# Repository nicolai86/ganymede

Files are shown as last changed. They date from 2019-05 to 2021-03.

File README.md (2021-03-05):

# Ganymede
the Ganymede keyboard. An ARM based, split ergonomic keyboard.

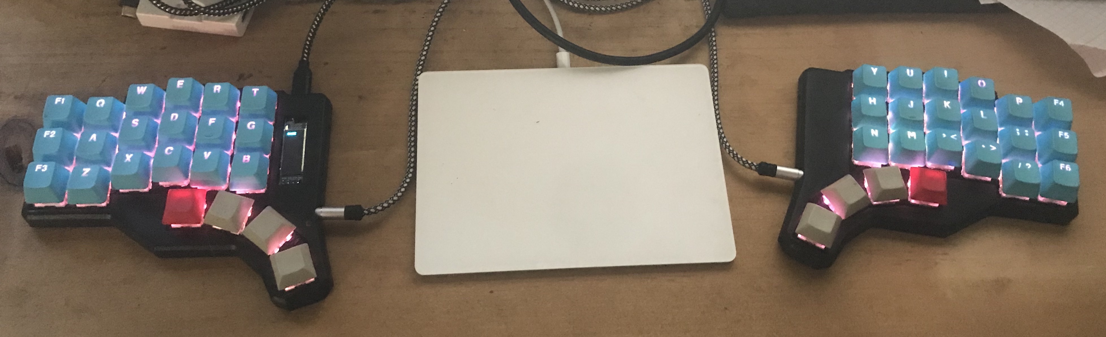
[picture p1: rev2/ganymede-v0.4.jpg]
current revision


## changelog 

### v0.5 / rev3

<ul style="list-style-type: none; margin: 0; padding: 0;">
    <li>+ choc support</li>
    <li>+ I2C eeprom (M24M01)</li>
    <li>- cherry mx support</li>
</ul>

### v0.4 / rev2

<ul style="list-style-type: none; margin: 0; padding: 0;">
    <li>+ per key RGB backlight</li>
    <li>+ 9 RGB underglow</li>
    <li>+ fully enclosed, 3d printable case with tenting support</li>
    <li>- flippable PCB</li>
</ul>

### v0.3 / rev1

<ul style="list-style-type: none; margin: 0; padding: 0;">
    <li>&#8226; OLED support (SSD1306 compatible)</li>
    <li>&#8226; ARM based (STM32F303CCT6)</li>
    <li>&#8226; QMK supported</li>
    <li>&#8226; flippable PCB</li>
    <li>&#8226; hot-swappable switches (using kailh-mx sockets)</li>
    <li>&#8226; mostly 0402 components</li>
</ul>

# qmk setup

- clone qmk 0.11.55
- add ganymede as a submodule: `git submodule add https://github.com/nicolai86/ganymede.git keyboards/ganymede`
- flash your ganymede: `make ganymede/rev3:default:dfu-util`

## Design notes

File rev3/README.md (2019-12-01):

# revision 0.5

There is no build guide for revision 0.5

## image

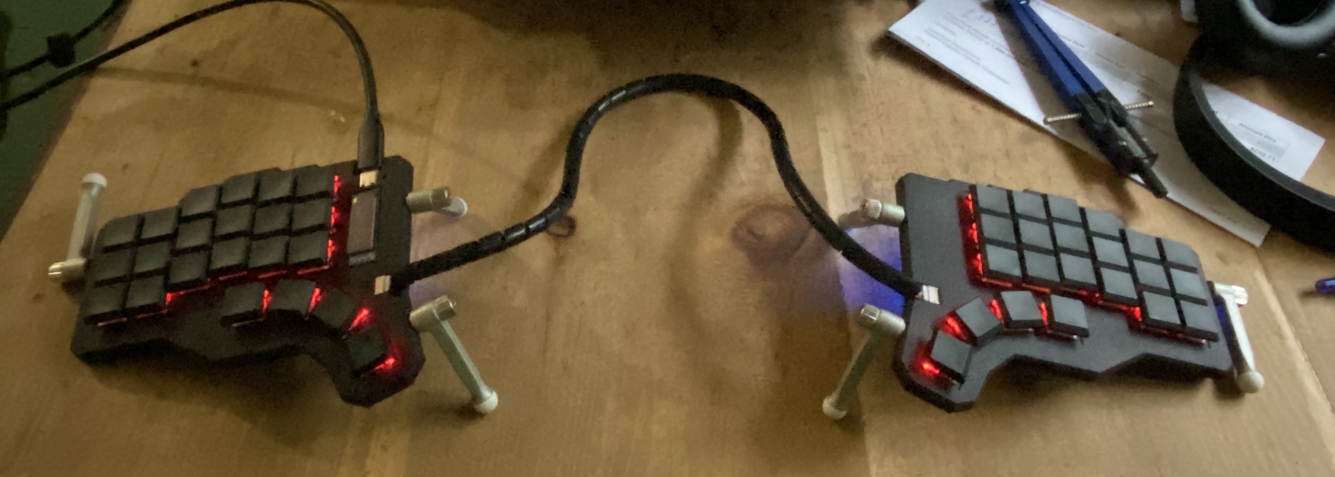
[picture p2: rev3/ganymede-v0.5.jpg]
left-right


## case

This revision comes with a fully enclosed case which can be 3d printed.
I've successfully 3d printed the case using SLS with Nylon 12:

However I need to update the existing case for the v0.5.1 PCB first

## gerbers

- [left side](./v0.5.1-left.zip)
- [right side](./v0.5.1-right.zip)

## BOM

- [left side](./v0.5.1-left.txt)
- [right side](./v0.5.1-right.txt)

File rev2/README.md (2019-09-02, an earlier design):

# revision 0.4

There is no build guide for revision 0.4 as it is mostly identical to revision 0.3;
The gerber files for this revision are available: [left hand (v0.4.1)](./left-0.4.1.zip) and [right hand (v0.4.0)](./right-0.4.0.zip).

## left side

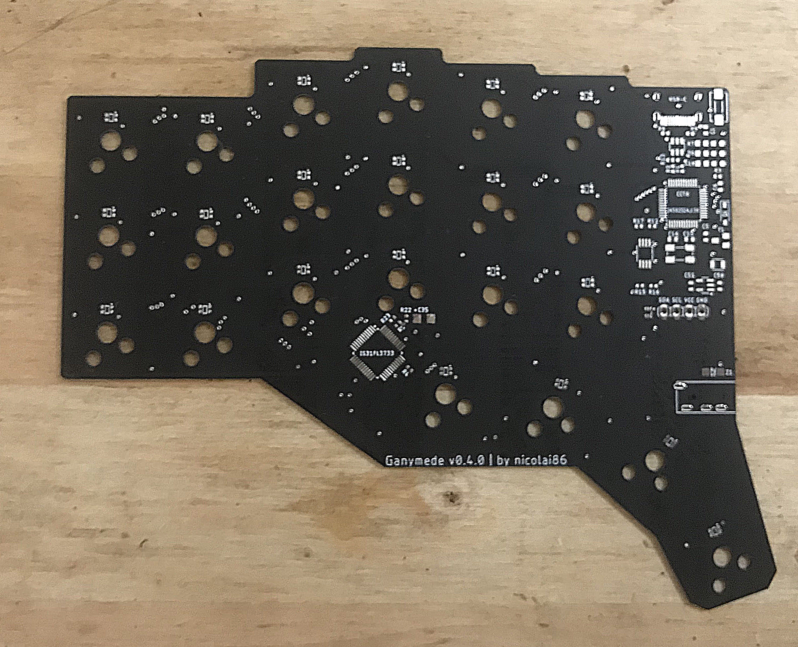
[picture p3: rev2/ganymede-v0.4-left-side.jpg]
left-top


## right side 

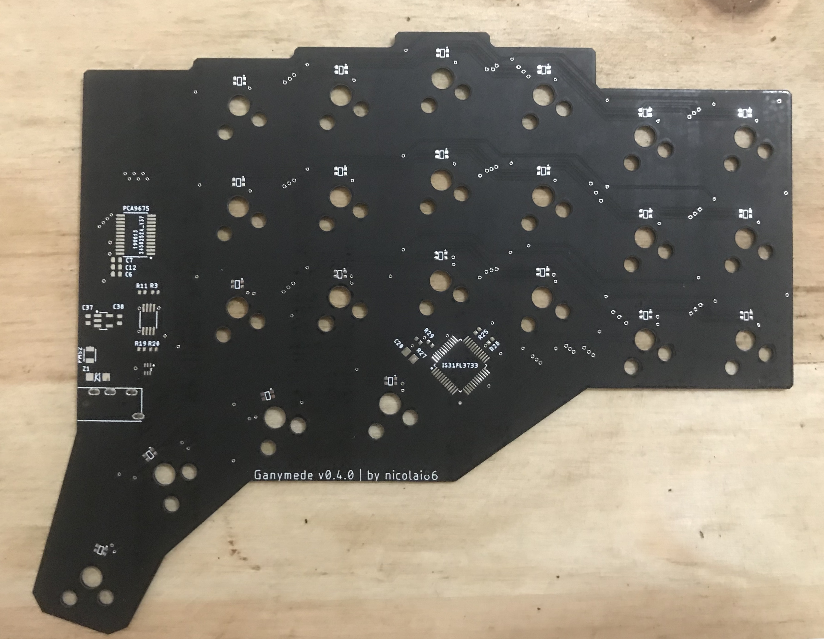
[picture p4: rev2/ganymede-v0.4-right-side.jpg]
right-top


## case

This revision comes with a fully enclosed case which can be 3d printed. [STL](./case-v0.4.zip).
I've successfully 3d printed the case using ABS with the following resolution and 100% infill each:

- [left top (100μm)](./case-v0.4/2-1x-left_upper-original.stl)
- [left bottom plate (200μm)](./case-v0.4/1-1x-left_plate-original.stl)
- [right top (100μm)](./case-v0.4/4-1x-right_upper-original.stl)
- [right bottom plate (200μm)](./case-v0.4/3-1x-right_plate-original.stl)

## Bill of Materials

- [left side](./ganymede-v0.4-left-side.bom.csv)
- [right side](./ganymede-v0.4-right-side.bom.csv)

You can find all parts on either lcsc.com or mouser.

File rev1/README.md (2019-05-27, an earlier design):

# revision 0.3

There is no build guide for rev 0.3 for now; See the assembled pictures for details; 
The gerber files for this revision are available in [gerber.zip](./gerber.zip).

Note that all decoupling capacitors are placed on the opposite side.

## left side (master)

### top

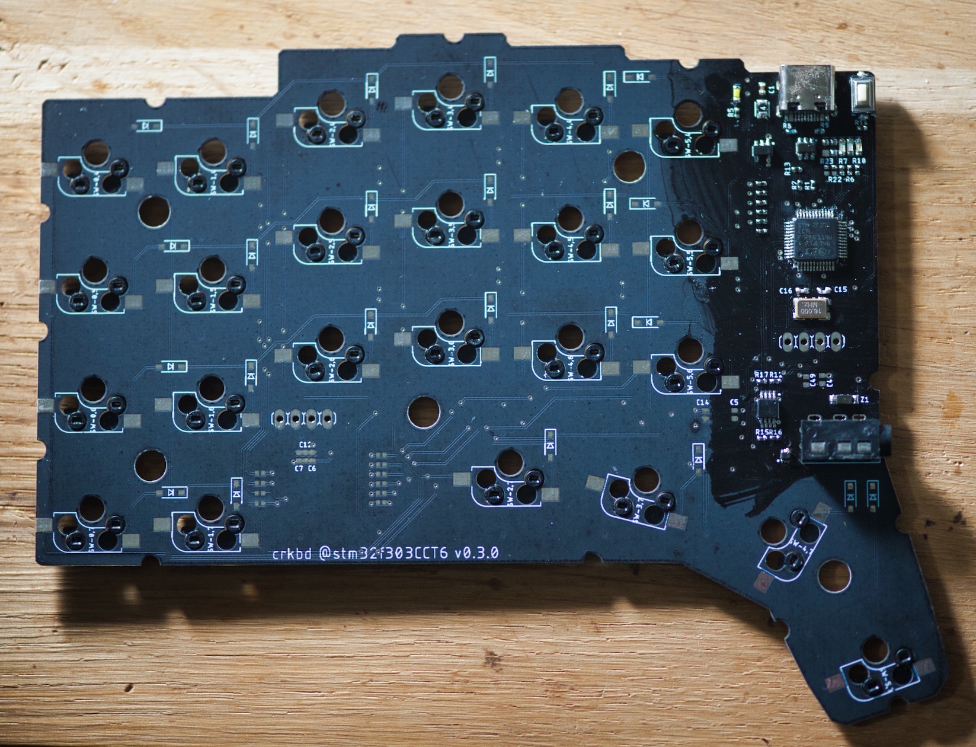
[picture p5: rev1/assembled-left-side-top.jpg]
left-top


important:
- capacitor for USB is placed on top
- resistors for primary I2C bus are placed on top
- resistors for the columns of the key matrix are placed on top

### bottom

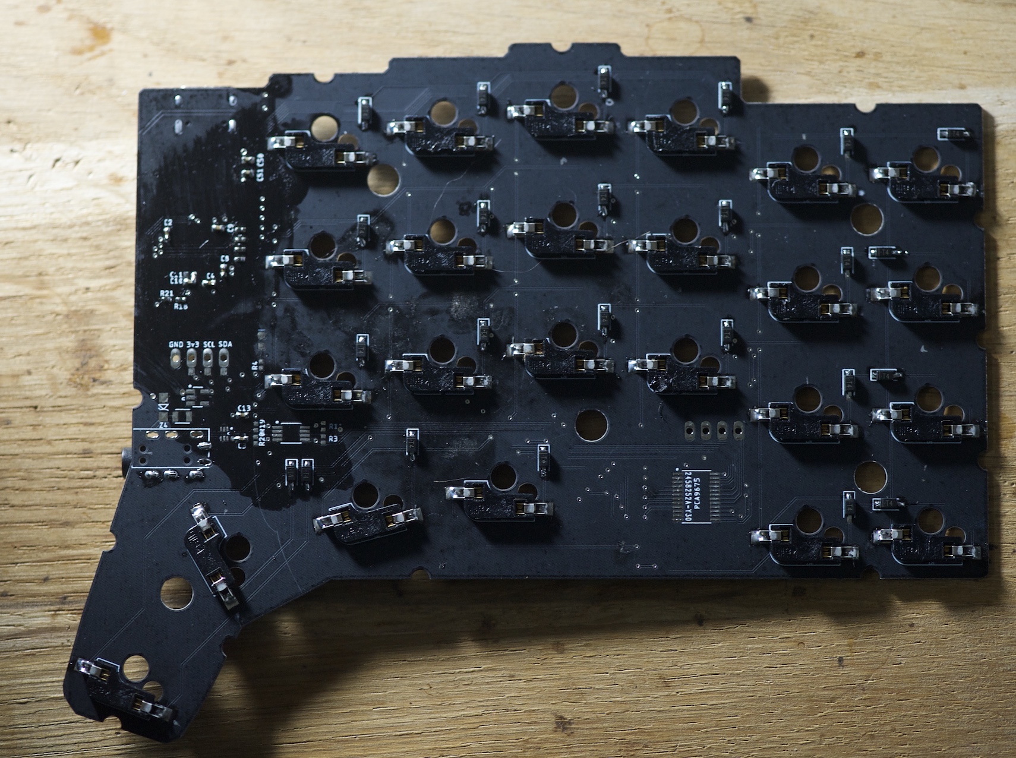
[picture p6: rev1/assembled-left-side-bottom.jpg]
left-bottom


important:
- all MX sockets are placed on the bottom
- all diodes are placed on the bottom
- capacitors for voltage regular are placed on the bottom
- capacitors for STM32F303 are placed on the bottom
- capacitors for PCA9617A are placed on the bottom
- resistors for second I2C bus are placed on the bottom
- resistors for the rows of the key matrix are placed on the bottom

## right side 

### top

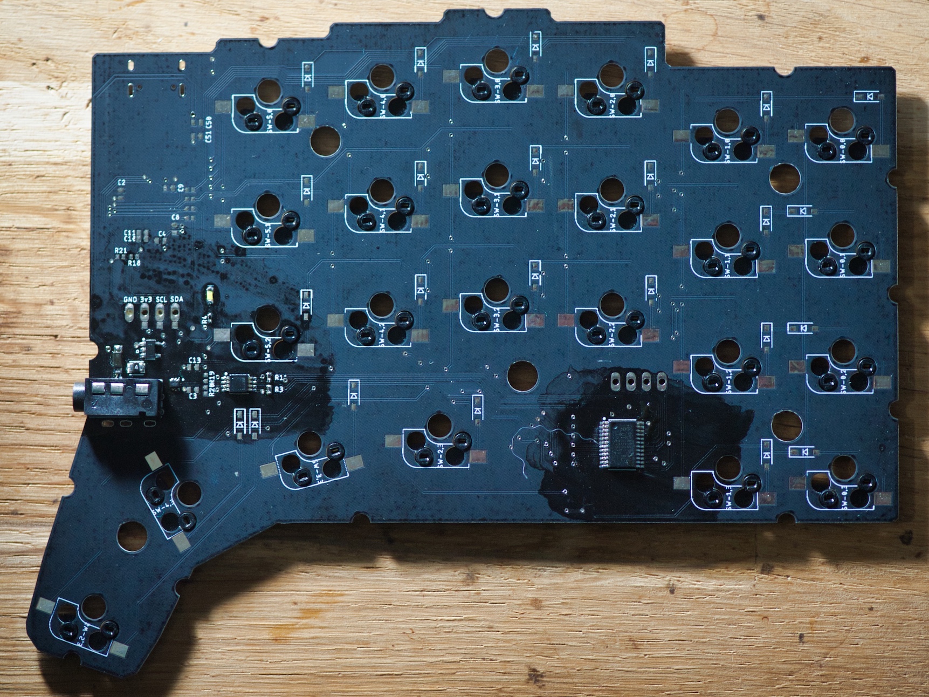
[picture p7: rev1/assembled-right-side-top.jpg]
right-top


important: 
- resistors for primary I2C bus are placed on top

### bottom

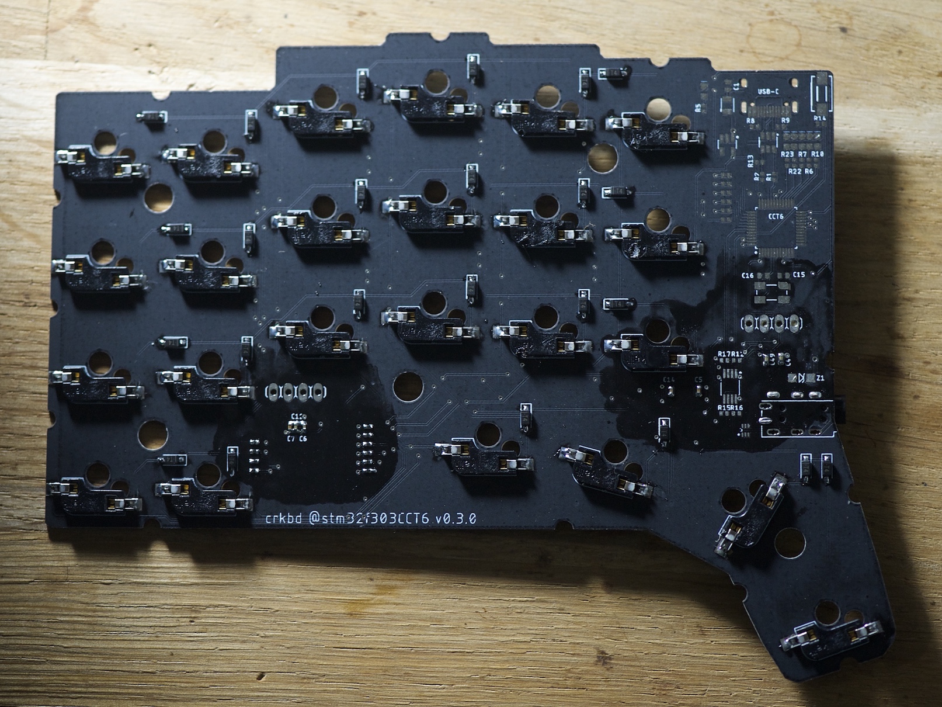
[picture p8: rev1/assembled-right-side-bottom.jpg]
right-bottom


important:
- all MX sockets are placed on the bottom
- all diodes are placed on the bottom
- capacitors for PCA9617A are placed on the bottom
- capacitors for PCA9675 are placed on the bottom
- capacitors for voltage regular are placed on the bottom
- all resistors for the key matrix are on the bottom

## Bill of Materials

|Qty|Value |Device |Package |
|---|:---:|:---:|:---:|
|7  |LED0603 |LED-0603 |0603 |
|1  |PINHD-1X4 |1X04 | |
|2  |3.5JACK320A |3.5JACK320A |PJ-320A |
|9  |100nF |C-USC0402 |0402 |
|1  |10nF |C-USC0402 |0402 |
|6  |1uF |C-USC0402 |0402 |
|2  |22pf |C-USC0402 |0402 |
|2  |4.7uF |C-USC0402 |0402 |
|1  |ABM3B |ABM3B |5X3.2 |
|1  |switch |DTSM-3 |DTSM-3 |
|48 |MX-SOCKET |MX-SOCKETSWITCH_PLATE |MX-SOCKET-3P |
|48 |1N4148 |1N4148 |SOD123 |
|1  |OLED |PINHD-1X4 |1X04 |
|2  |PCA9617A |PCA9617ATSSOP8 |TSSOP8 |
|1  |PCA9675 |PCA9675SOP24 |SOP24 |
|2  |PSMD050 |PSMD0500805 |0804 |
|1  |STM32F302_303CCT6 |STM32F302_303C2LQFP48-7X7 |TQFN48 |
|2  |TPD2E1B06 |TPD2E1B06 |SOT |
|1  |TYPE-C-31-M-12 |TYPE-C-31-M-12 |TYPE-C-31-M-12 |
|1  |USBLC6-2SC6 |USBLC6-2SC6 |SOT-23-6L |
|2  |XC6201 |XC6201 |SOT95P270X110-5 |
|2  |ZENER |ZENER-DIODESOD123 |SOD123 |
|25 |470 |R-US_R0402 |0402 |
|2  |5k1 |R-US_R0402 |0402 |
|2  |22 |R-US_R0402 |0402 |
|1  |10k |R-US_R0402 |0402 |
|2  |1k |R-US_R0402 |0402 |
|8  |1k4 |R-US_R0402 |0402 |
|1  |1k5 |R-US_R0402 |0402 |

You can find all parts on either lcsc.com or mouser.

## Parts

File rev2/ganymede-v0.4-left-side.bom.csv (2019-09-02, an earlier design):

Qty | Value | Device | Package | Parts | Description | SPICEPREFIX
3 |  | LED0603 | LED-0603 | D43, D52, D53 | LED (Generic)
4 | 100k | R-US_R0402 | R0402 | R3, R5, R22, R23 | RESISTOR, American symbol | R
10 | 100nF | C-USC0402 | C0402 | C1, C2, C3, C4, C8, C13, C28, C30, C32, C34 | CAPACITOR, American symbol | C
1 | 10nF | C-USC0402 | C0402 | C11 | CAPACITOR, American symbol | C
23 | 1N4148-0805SOD123 | 1N4148-0805SOD123 | SOD3715X135 | D1, D2, D3, D4, D5, D6, D7, D8, D9, D10, D11, D12, D13, D14, D15, D16, D17, D18, D19, D20, D21, D22, D23 | Diode: switching; SMD; 75V; 150mA; 4ns; 0805
6 | 1k4 | R-US_R0402 | R0402 | R12, R15, R16, R17, R18, R21 | RESISTOR, American symbol | R
1 | 1k5 | R-US_R0402 | R0402 | R13 | RESISTOR, American symbol | R
3 | 1uF | C-USC0402 | C0402 | C10, C50, C51 | CAPACITOR, American symbol | C
1 | 20k | R-US_R0402 | R0402 | R4 | RESISTOR, American symbol | R
2 | 22 | R-US_R0402 | R0402 | R1, R2 | RESISTOR, American symbol | R
2 | 22pf | C-USC0402 | C0402 | C15, C16 | CAPACITOR, American symbol | C
1 | 22uF/10V | C-USC1206 | C1206 | C35 | CAPACITOR, American symbol | C
1 | 3.5JACK320A | 3.5JACK320A | 320A | U$6
31 | 3528-RGB-LED1.6X1.6 | 3528-RGB-LED1.6X1.6 | 19-237/R6GHBHC-M01/2T | D0,0, D0,1, D0,2, D1,0, D1,1, D1,2, D2,0, D2,1, D2,2, D2,3, D3,0, D3,1, D3,2, D3,3, D4,0, D4,1, D4,2, D4,3, D5,0, D5,1, D5,2, D5,3, D5,4, D5,5, D5,6, D5,8, D5,9, D5,10, D5,12, D5,13, D5,14
1 | 4.7uF | C-USC0402 | C0402 | C9 | CAPACITOR, American symbol | C
10 | 470 | R-US_R0402 | R0402 | COL1R, COL2R, COL3R, COL4R, COL5R, COL6R, ROW1R, ROW2R, ROW3R, ROW4R | RESISTOR, American symbol | R
3 | 470 | R-US_R0603 | R0603 | R6, R7, R10 | RESISTOR, American symbol | R
5 | 47nF | C-USC0402 | C0402 | C27, C29, C31, C33, C36 | CAPACITOR, American symbol | C
2 | 4k7 | C-USC0402 | C0402 | C5, C6 | CAPACITOR, American symbol | C
2 | 5k1 | R-US_R0402 | R0402 | R8, R9 | RESISTOR, American symbol | R
1 | ABM3B | ABM3B | 5X3.2 | U$11
1 | BC847 | BC847 | SOT23 | T1 | NPN TRANSISTOR
1 | DTSM-3 | DTSM-3 | DTSM-3 | S2
1 | IS31FL3733ETQFP-48 | IS31FL3733ETQFP-48 | QFP50P900X900X120-48 | IS31FL3733
1 | OLED | SSD1306128X32 | 1X04 | JP1
1 | PCA9617ATSSOP8 | PCA9617ATSSOP8 | SOP65P490X110-8 | U$1
1 | PSMD0500805 | PSMD0500805 | RESC2113X80 | PMS1
1 | STM32F302_303C2LQFP48-7X7 | STM32F302_303C2LQFP48-7X7 | QFP50P900X900X160-48 | CCT6
22 | SWITCHMX-SOCKET | SWITCHMX-SOCKET | MX-SOCKET-3P | SW-0,0, SW-0,1, SW-0,2, SW-1,0, SW-1,1, SW-1,2, SW-2,0, SW-2,1, SW-2,2, SW-2,3, SW-3,0, SW-3,1, SW-3,2, SW-3,3, SW-4,0, SW-4,1, SW-4,2, SW-4,3, SW-5,0, SW-5,1, SW-5,2, SW-5,3
1 | TPD2E1B06 | TPD2E1B06 | SOT | U$2
1 | TYPE-C-31-M-12 | TYPE-C-31-M-12 | TYPE-C-31-M-12 | USB-C
1 | USBLC6-2SC6 | USBLC6-2SC6 | SOT-23-6L | VD1 | VERY LOW CAPACITANCE ESD PROTECTION 2 line
1 | XC6201 | XC6201 | SOT95P270X110-5 | P1 | XC6201P , linear regulator.
1 | ZENER-DIODESOD123 | ZENER-DIODESOD123 | SOD123 | Z1

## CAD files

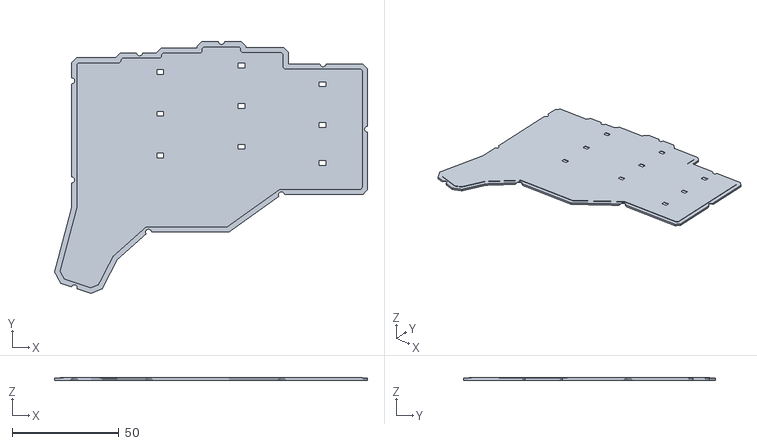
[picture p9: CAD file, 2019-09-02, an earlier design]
rev2/case-v0.4/3-1x-right_plate-original.stl
146.9 x 118.2 x 1.25

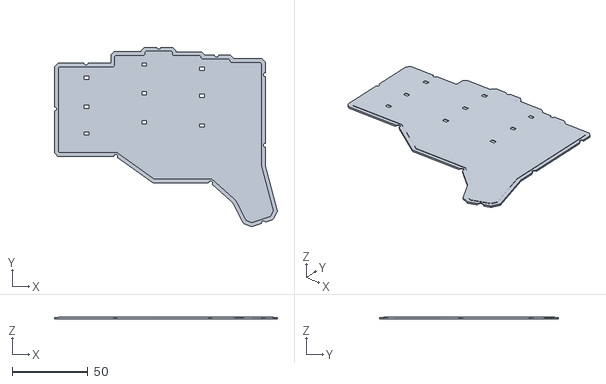
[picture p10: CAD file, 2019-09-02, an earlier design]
rev2/case-v0.4/1-1x-left_plate-original.stl
147.0 x 118.3 x 1.25

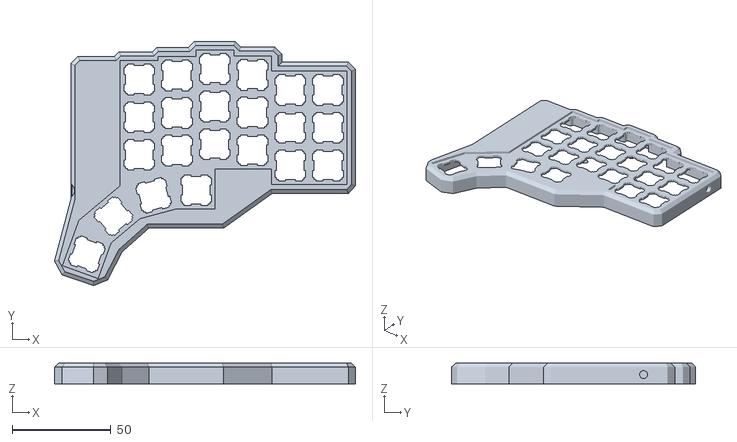
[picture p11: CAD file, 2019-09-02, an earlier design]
rev2/case-v0.4/4-1x-right_upper-original.stl
152.0 x 123.3 x 10.5

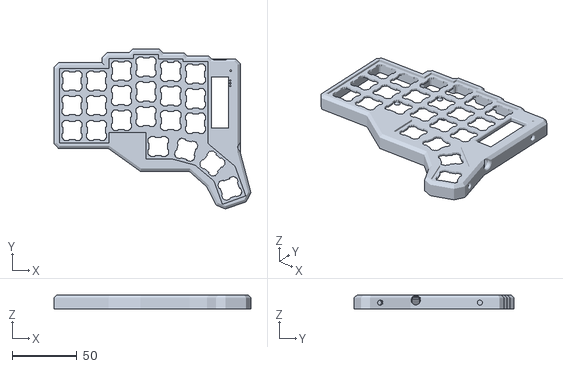
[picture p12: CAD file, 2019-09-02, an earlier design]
rev2/case-v0.4/2-1x-left_upper-original.stl
152.0 x 123.3 x 10.5

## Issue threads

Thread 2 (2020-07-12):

rev1 schematic wrong crystal value

ObviousInRetrospect, 2020-07-12:
I Built a rev1 an discovered that the schematic shows a 8mhz crystal but the firmware is configured for a 16mhz crystal (which matches the jpeg). No source files in the repo so I can't easily send a pull request with the correction.

Attaching a patch to configure the mcu for an 8mhz crystal in case anyone else repeats my error (having fixed the problem in software I wasn't motivated to replace the crystal).
[8mhz.txt](https://github.com/nicolai86/ganymede/files/4907829/8mhz.txt)

Would you consider adding at least the schematic and preferably the design files for rev3 to the repo? It's a nice keyboard. Given the components that lack silkscreen it would have been easier to assemble with access to the board files.

nicolai86, 2021-01-27:
Sorry about this @ObviousInRetrospect ! I didn't have enough 8MHz crystals so I switched to 16 MHz crystals at some pint.

It's a very important call out so I'll leave the issue open for anybody else that follows your path.

nicolai86, 2021-01-27:
also let me fix the missing schematics. another nice call out.

nicolai86, 2021-01-27:
https://github.com/nicolai86/ganymede/commit/9c96c2d28d5396f54fbc986f7e1ca9513a758c81 adds the schematic for rev2.

nicolai86, 2021-01-27:
https://github.com/nicolai86/ganymede/commit/9909a344b8d5b8e749dde967682d227af309a690 adds the schematic for rev3

nicolai86, 2021-01-27:
the design files for rev3 are already checked in - if you refer to the gerber files.
I can send you the eagle files separately if you like.

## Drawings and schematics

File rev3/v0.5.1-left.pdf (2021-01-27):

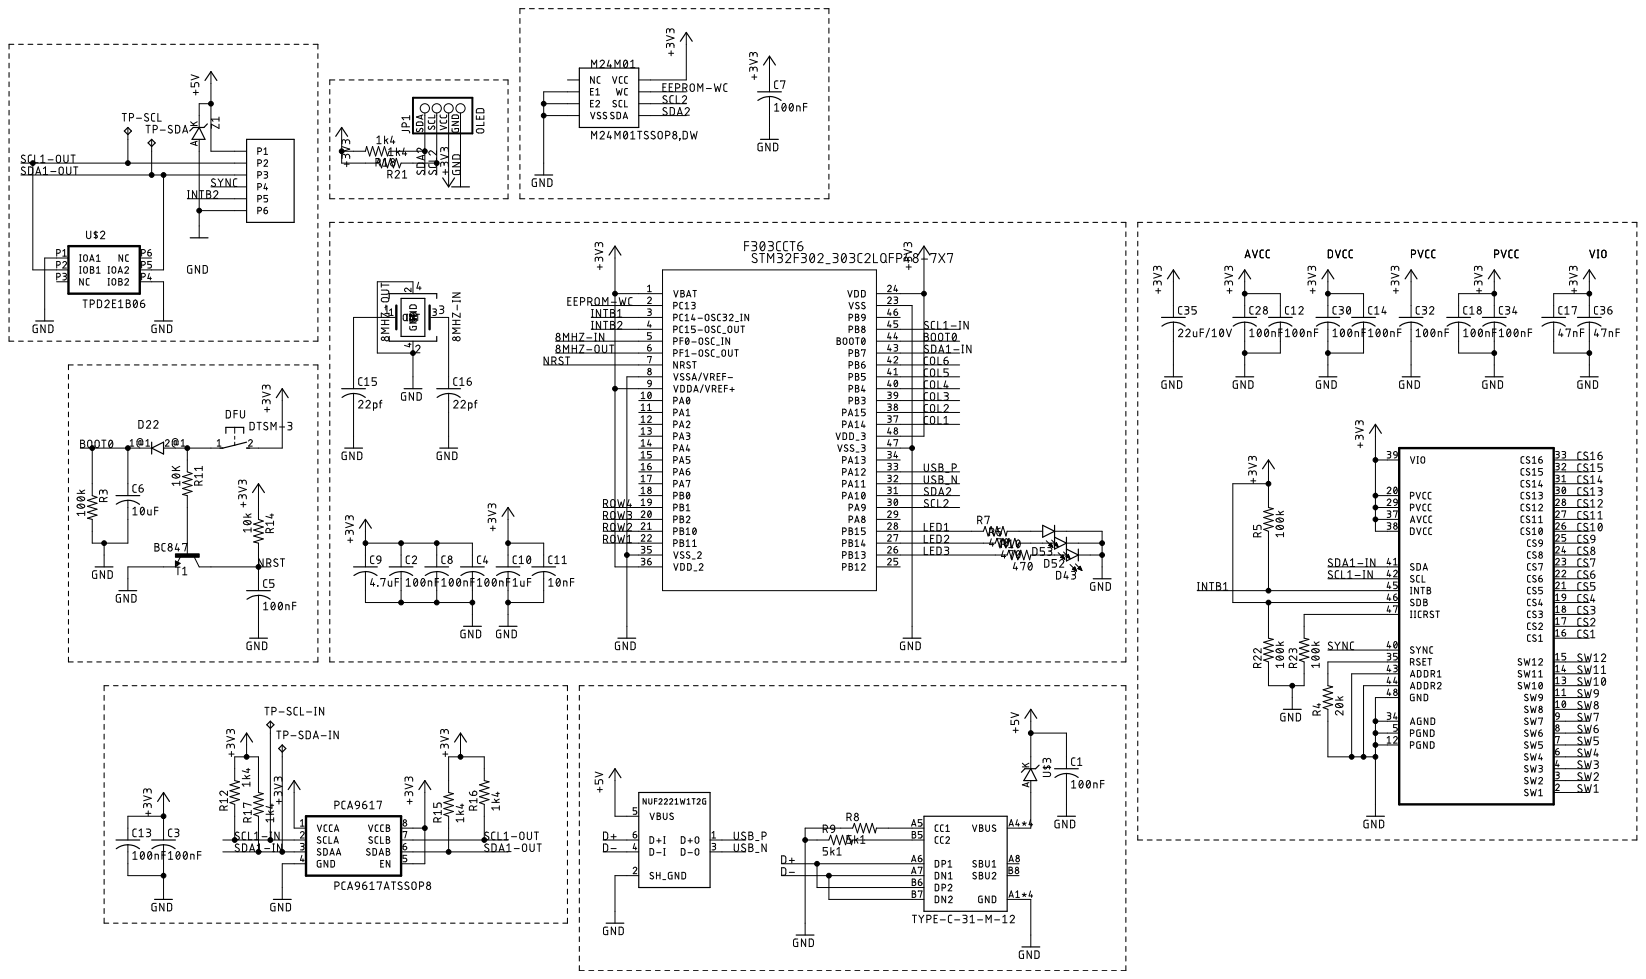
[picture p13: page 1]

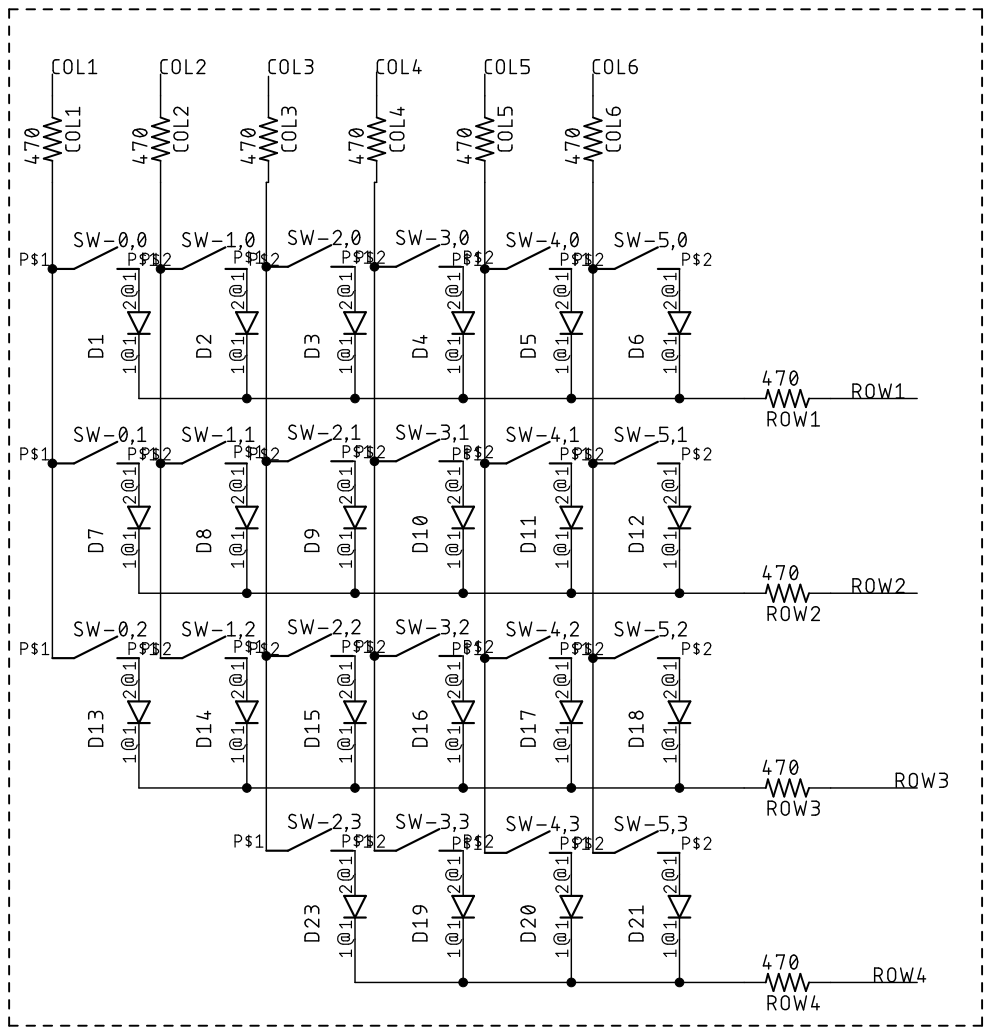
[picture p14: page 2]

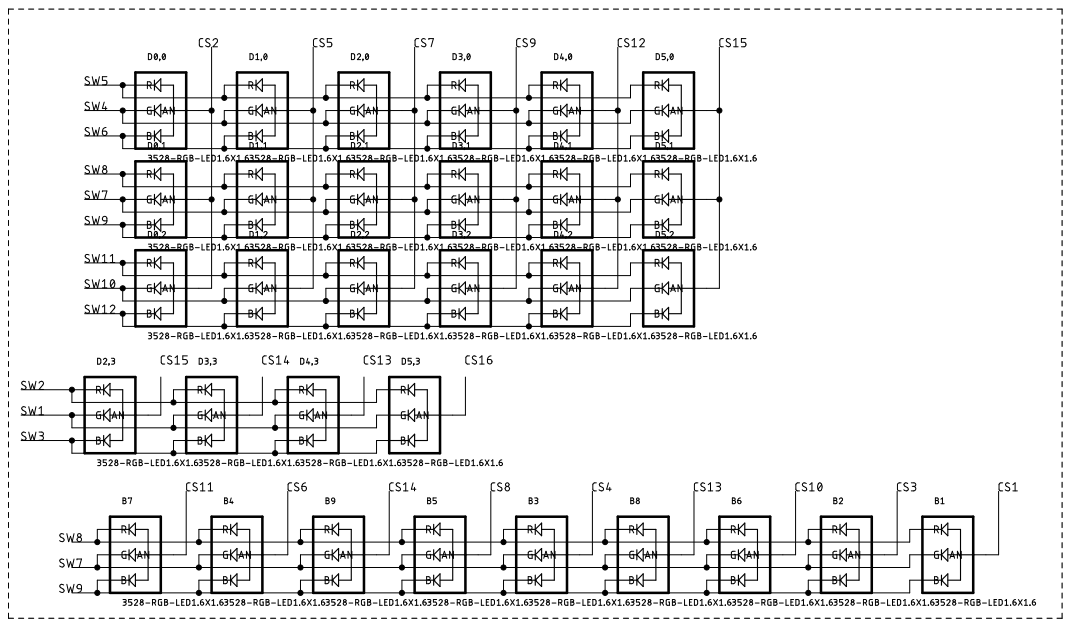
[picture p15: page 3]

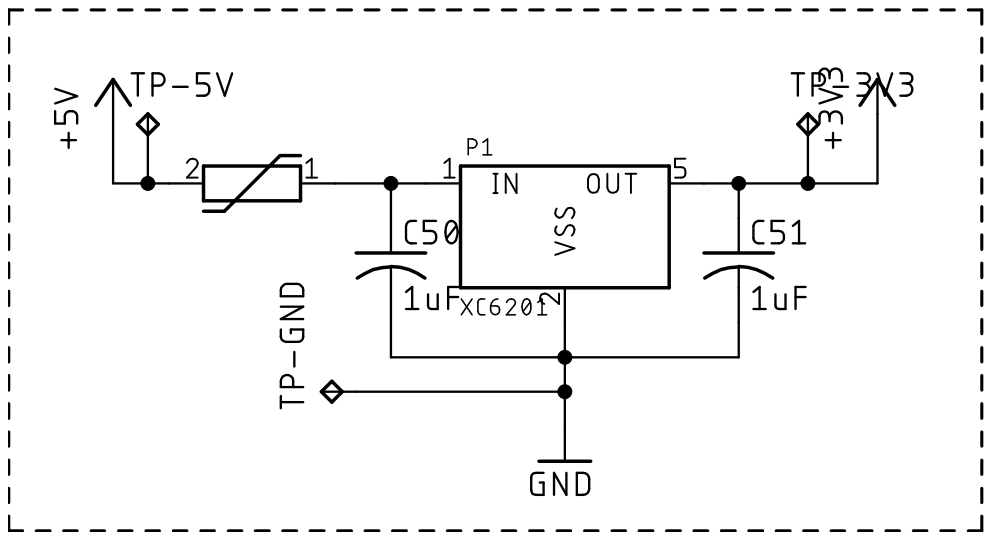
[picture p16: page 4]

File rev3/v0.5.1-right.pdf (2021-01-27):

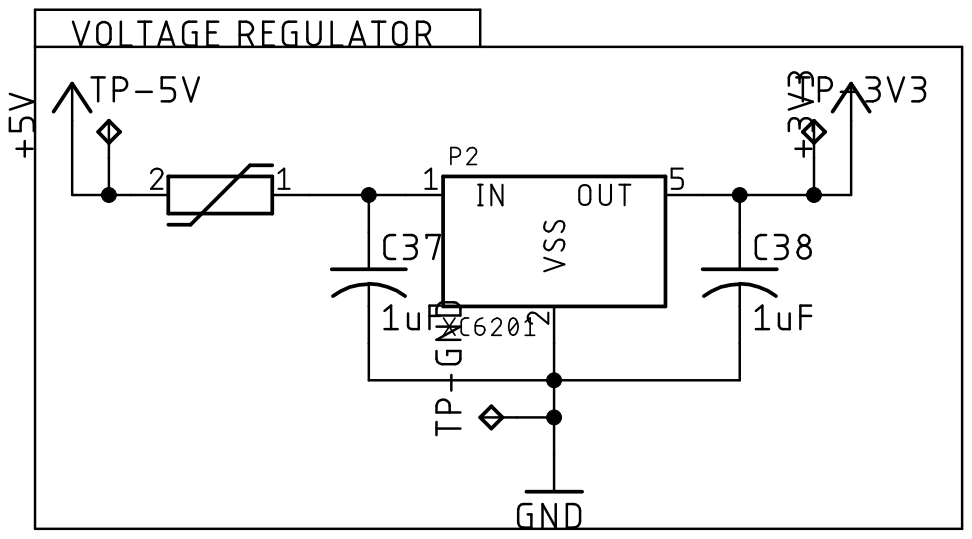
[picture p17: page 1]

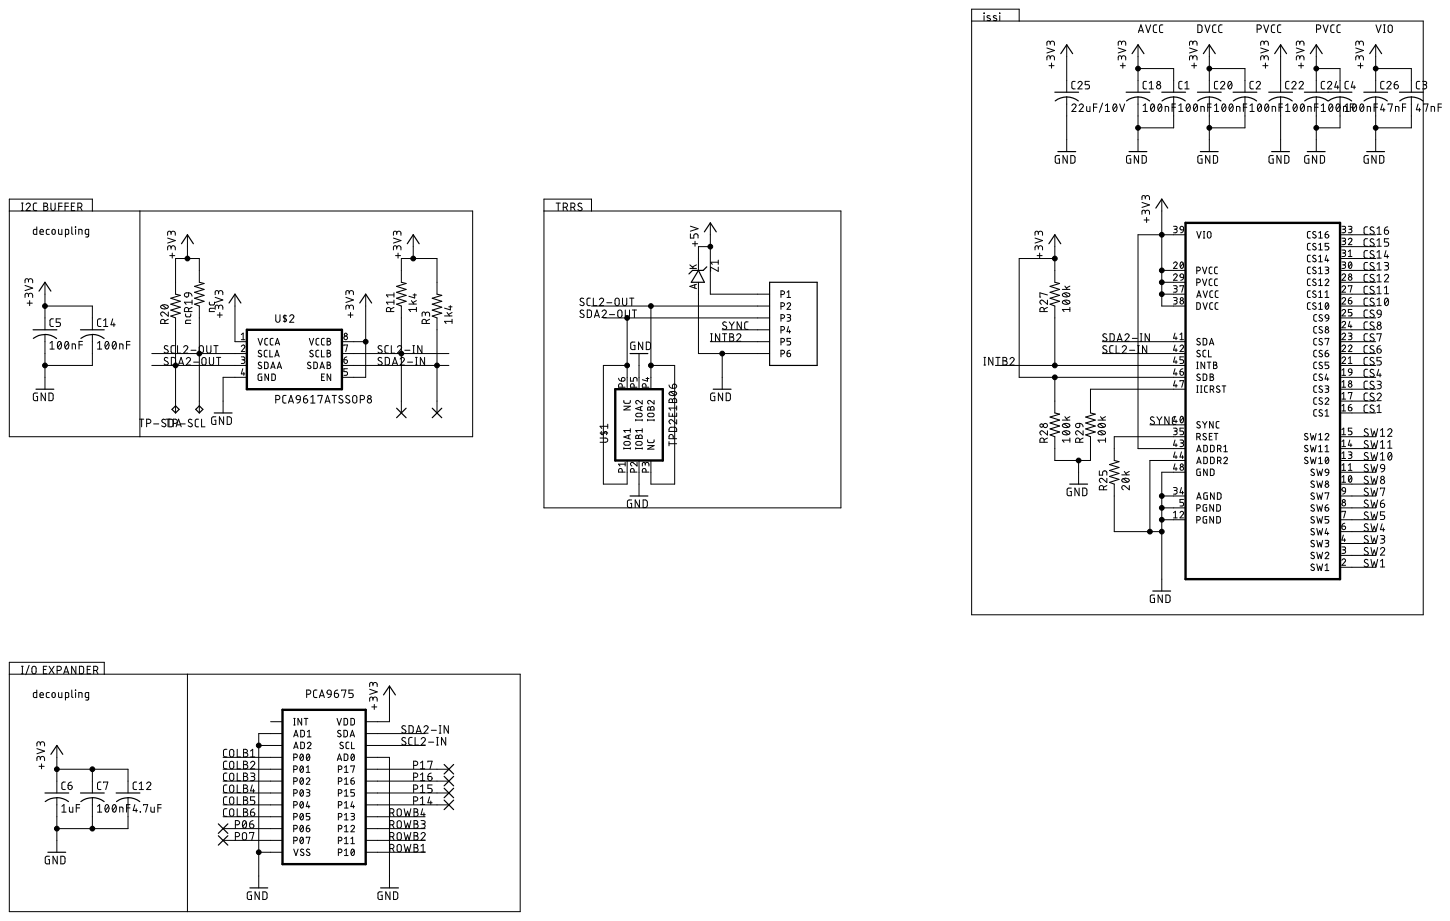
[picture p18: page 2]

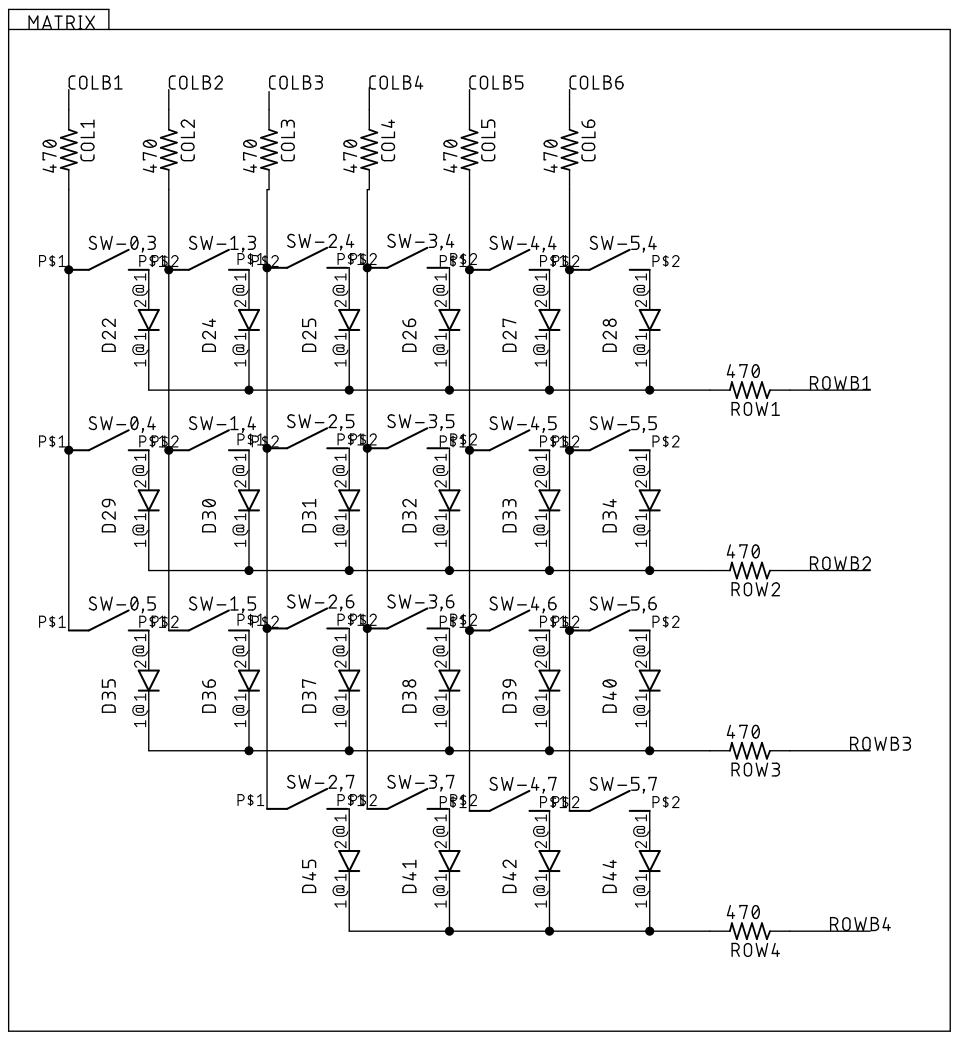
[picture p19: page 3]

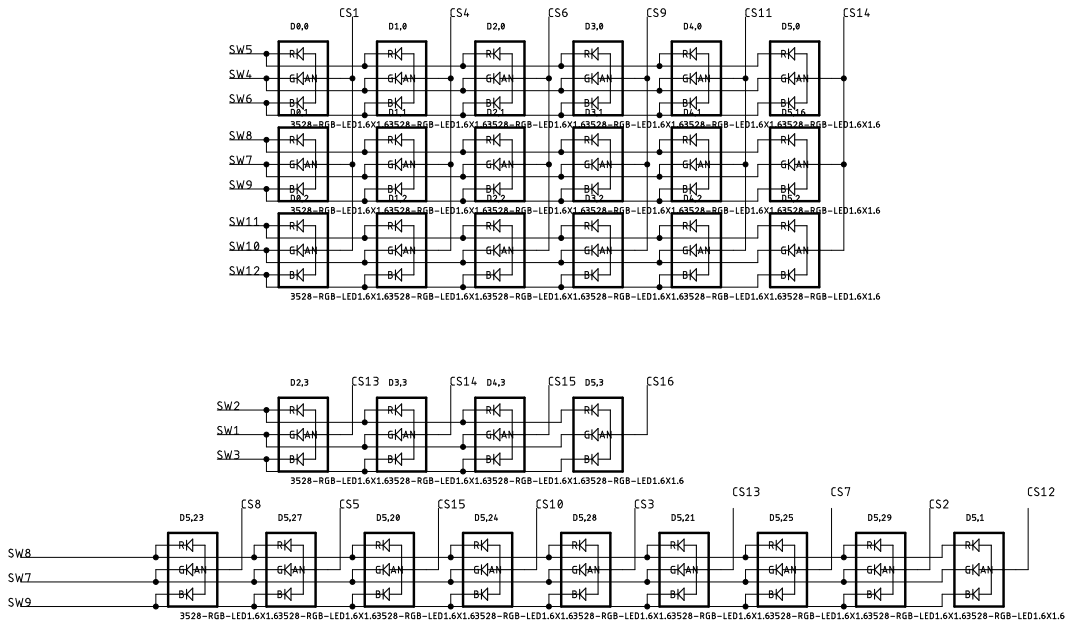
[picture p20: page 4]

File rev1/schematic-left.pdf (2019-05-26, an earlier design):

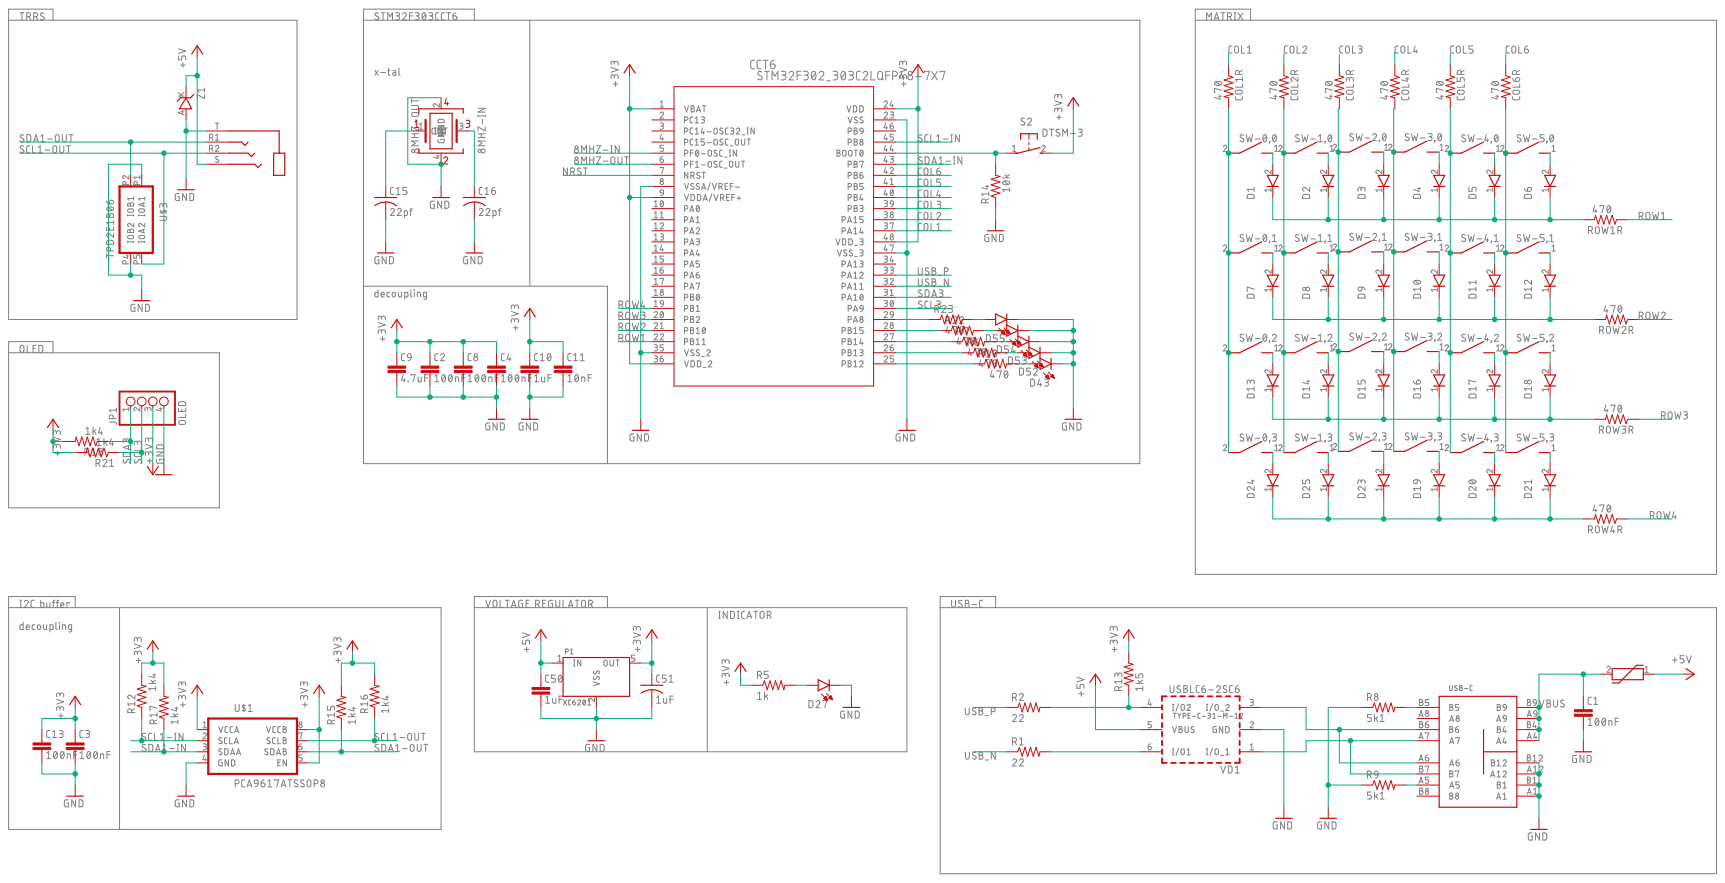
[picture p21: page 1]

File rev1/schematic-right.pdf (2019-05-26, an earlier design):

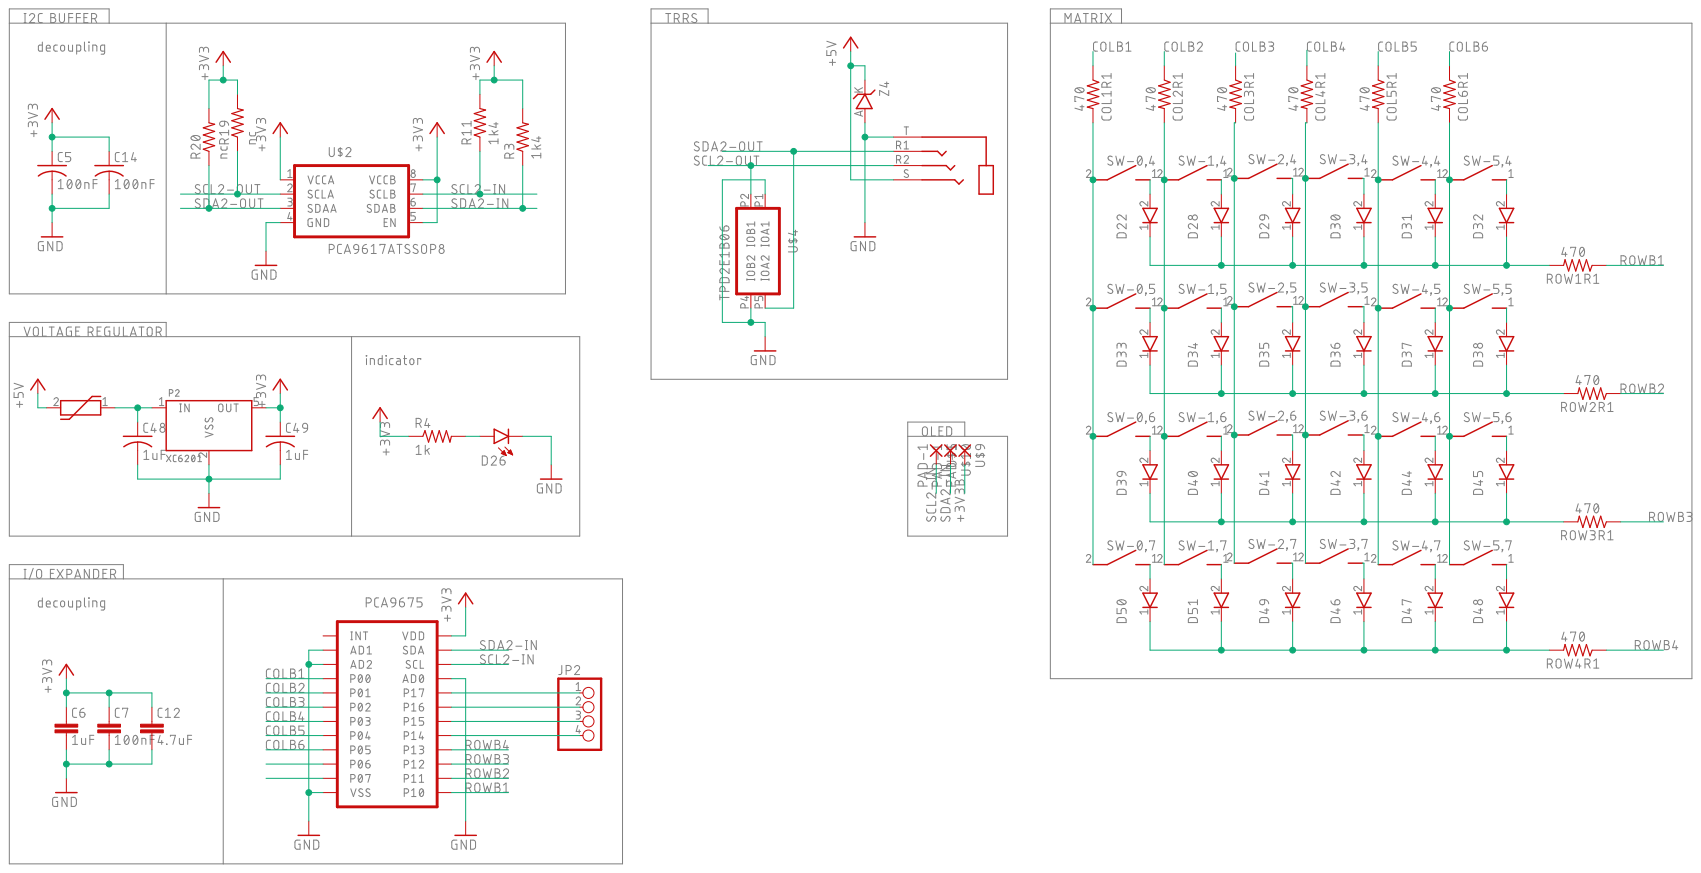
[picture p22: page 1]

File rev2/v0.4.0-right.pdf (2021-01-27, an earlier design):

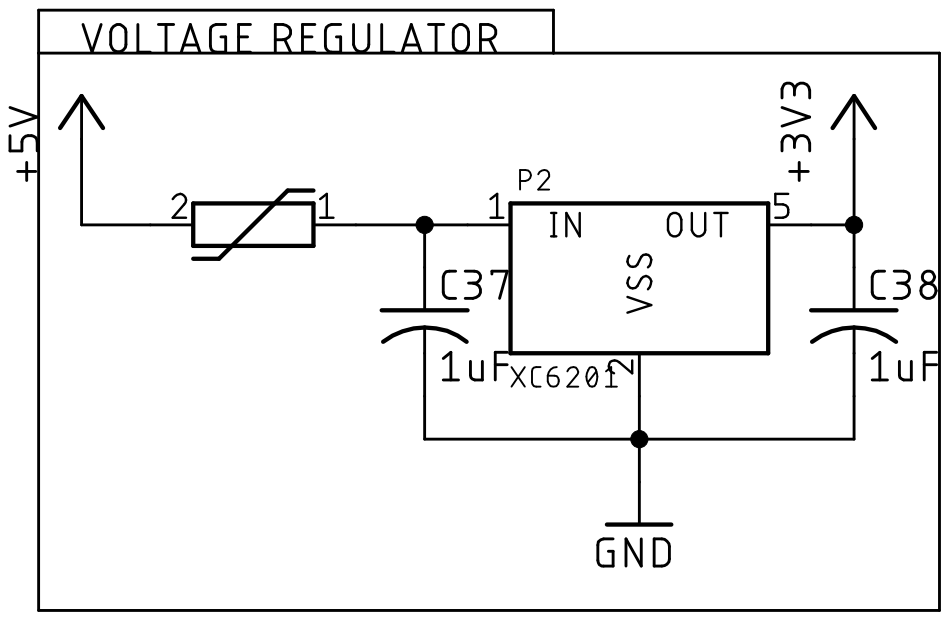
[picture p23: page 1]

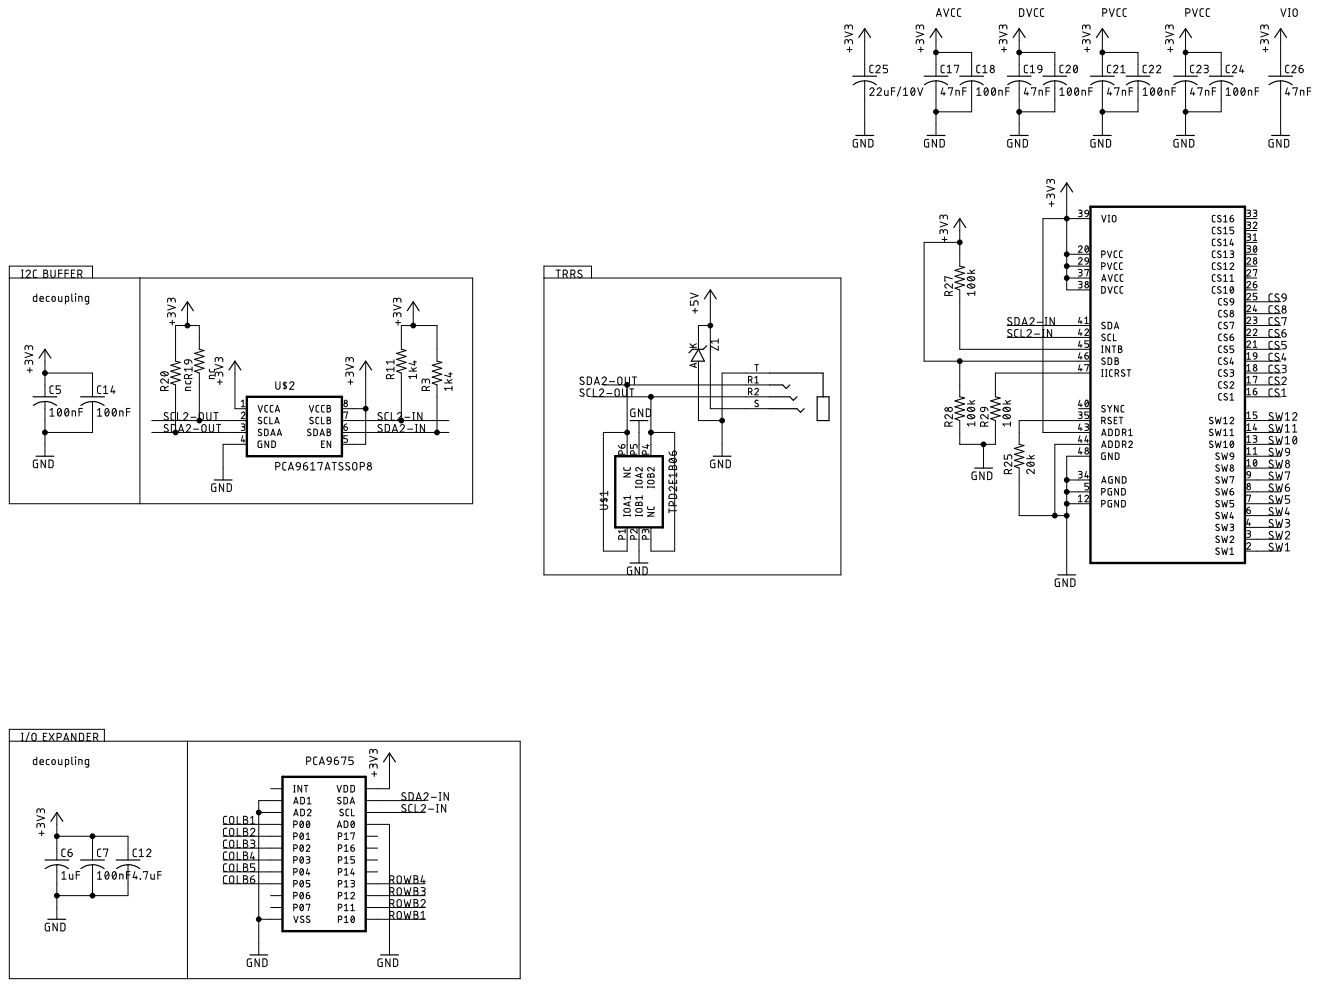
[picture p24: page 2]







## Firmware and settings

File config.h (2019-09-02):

#pragma once

#include "config_common.h"

#define STM32_HSECLK    16000000U

#define VENDOR_ID       0xFEED
#define PRODUCT_ID      0x3061
#define DEVICE_VER      0x0003
#define MANUFACTURER    nicolai86
#define PRODUCT         Ganymede
#define DESCRIPTION     An split ergonomic keyboard based on the crkbd

#define STM32_BOOTLOADER_ADDRESS 0x1FFFD800

#define MATRIX_ROWS 8
#define MATRIX_ROWS_PER_SIDE 4
#define MATRIX_COLS 6

#define MATRIX_ROW_PINS {B11, B10, B2, B1}
#define MATRIX_COL_PINS {A14, A15, B3, B4, B5, B6 }
#define UNUSED_PINS {}
#define DIODE_DIRECTION COL2ROW

// PCA9675
#define PCA9675_I2C_ADDR       0x20
#define PCA9675_I2C_RESET_ADDR 0x00
#define PCA9675_I2C_RESET_CMD  0x06
#define PCA9675_I2C_TIMEOUT 100

#define I2C1_BANK  GPIOB
#define I2C_DRIVER I2CD1
#define I2C1_SDA 7
#define I2C1_SCL 8

#define DRIVER_COUNT 1
#define DRIVER_LED_TOTAL 64
#define ISSI_ADDR_1 0x50
#define ISSI_ADDR_2 0x53

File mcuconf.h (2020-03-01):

/*
    ChibiOS - Copyright (C) 2006..2018 Giovanni Di Sirio

    Licensed under the Apache License, Version 2.0 (the "License");
    you may not use this file except in compliance with the License.
    You may obtain a copy of the License at

        http://www.apache.org/licenses/LICENSE-2.0

    Unless required by applicable law or agreed to in writing, software
    distributed under the License is distributed on an "AS IS" BASIS,
    WITHOUT WARRANTIES OR CONDITIONS OF ANY KIND, either express or implied.
    See the License for the specific language governing permissions and
    limitations under the License.
*/

#ifndef MCUCONF_H
#define MCUCONF_H

/*
 * STM32F3xx drivers configuration.
 * The following settings override the default settings present in
 * the various device driver implementation headers.
 * Note that the settings for each driver only have effect if the whole
 * driver is enabled in halconf.h.
 *
 * IRQ priorities:
 * 15...0       Lowest...Highest.
 *
 * DMA priorities:
 * 0...3        Lowest...Highest.
 */

#define STM32F3xx_MCUCONF
#define STM32F303_MCUCONF

/*
 * HAL driver system settings.
 */
#define STM32_NO_INIT                       FALSE
#define STM32_PVD_ENABLE                    FALSE
#define STM32_PLS                           STM32_PLS_LEV0
#define STM32_HSI_ENABLED                   TRUE
#define STM32_LSI_ENABLED                   TRUE
#define STM32_HSE_ENABLED                   TRUE
#define STM32_LSE_ENABLED                   FALSE
#define STM32_SW                            STM32_SW_PLL
#define STM32_PLLSRC                        STM32_PLLSRC_HSE
#define STM32_PREDIV_VALUE                  2
#define STM32_PLLMUL_VALUE                  9
#define STM32_HPRE                          STM32_HPRE_DIV1
#define STM32_PPRE1                         STM32_PPRE1_DIV2
#define STM32_PPRE2                         STM32_PPRE2_DIV2
#define STM32_MCOSEL                        STM32_MCOSEL_NOCLOCK
#define STM32_ADC12PRES                     STM32_ADC12PRES_DIV1
#define STM32_ADC34PRES                     STM32_ADC34PRES_DIV1
#define STM32_USART1SW                      STM32_USART1SW_PCLK
#define STM32_USART2SW                      STM32_USART2SW_PCLK
#define STM32_USART3SW                      STM32_USART3SW_PCLK
#define STM32_UART4SW                       STM32_UART4SW_PCLK
#define STM32_UART5SW                       STM32_UART5SW_PCLK
#define STM32_I2C1SW                        STM32_I2C1SW_SYSCLK
#define STM32_I2C2SW                        STM32_I2C2SW_SYSCLK
#define STM32_TIM1SW                        STM32_TIM1SW_PCLK2
#define STM32_TIM8SW                        STM32_TIM8SW_PCLK2
#define STM32_RTCSEL                        STM32_RTCSEL_LSI
#define STM32_USB_CLOCK_REQUIRED            TRUE
#define STM32_USBPRE                        STM32_USBPRE_DIV1P5

/*
 * IRQ system settings.
 */
#define STM32_IRQ_EXTI0_PRIORITY            6
#define STM32_IRQ_EXTI1_PRIORITY            6
#define STM32_IRQ_EXTI2_PRIORITY            6
#define STM32_IRQ_EXTI3_PRIORITY            6
#define STM32_IRQ_EXTI4_PRIORITY            6
#define STM32_IRQ_EXTI5_9_PRIORITY          6
#define STM32_IRQ_EXTI10_15_PRIORITY        6
#define STM32_IRQ_EXTI16_PRIORITY           6
#define STM32_IRQ_EXTI17_PRIORITY           15
#define STM32_IRQ_EXTI18_PRIORITY           6
#define STM32_IRQ_EXTI19_PRIORITY           15
#define STM32_IRQ_EXTI20_PRIORITY           15
#define STM32_IRQ_EXTI21_22_29_PRIORITY     6
#define STM32_IRQ_EXTI30_32_PRIORITY        6
#define STM32_IRQ_EXTI33_PRIORITY           6
#define STM32_IRQ_TIM1_BRK_TIM15_PRIORITY   7
#define STM32_IRQ_TIM1_UP_TIM16_PRIORITY    7
#define STM32_IRQ_TIM1_TRGCO_TIM17_PRIORITY 7
#define STM32_IRQ_TIM1_CC_PRIORITY          7

/*
 * ADC driver system settings.
 */
#define STM32_ADC_DUAL_MODE                 FALSE
#define STM32_ADC_COMPACT_SAMPLES           FALSE
#define STM32_ADC_USE_ADC1                  FALSE
#define STM32_ADC_USE_ADC2                  FALSE
#define STM32_ADC_USE_ADC3                  FALSE
#define STM32_ADC_USE_ADC4                  FALSE
#define STM32_ADC_ADC1_DMA_STREAM           STM32_DMA_STREAM_ID(1, 1)
#define STM32_ADC_ADC2_DMA_STREAM           STM32_DMA_STREAM_ID(2, 1)
#define STM32_ADC_ADC3_DMA_STREAM           STM32_DMA_STREAM_ID(2, 5)
#define STM32_ADC_ADC4_DMA_STREAM           STM32_DMA_STREAM_ID(2, 2)
#define STM32_ADC_ADC1_DMA_PRIORITY         2
#define STM32_ADC_ADC2_DMA_PRIORITY         2
#define STM32_ADC_ADC3_DMA_PRIORITY         2
#define STM32_ADC_ADC4_DMA_PRIORITY         2
#define STM32_ADC_ADC12_IRQ_PRIORITY        5
#define STM32_ADC_ADC3_IRQ_PRIORITY         5
#define STM32_ADC_ADC4_IRQ_PRIORITY         5
#define STM32_ADC_ADC1_DMA_IRQ_PRIORITY     5
#define STM32_ADC_ADC2_DMA_IRQ_PRIORITY     5
#define STM32_ADC_ADC3_DMA_IRQ_PRIORITY     5
#define STM32_ADC_ADC4_DMA_IRQ_PRIORITY     5
#define STM32_ADC_ADC12_CLOCK_MODE          ADC_CCR_CKMODE_AHB_DIV1
#define STM32_ADC_ADC34_CLOCK_MODE          ADC_CCR_CKMODE_AHB_DIV1

/*
 * CAN driver system settings.
 */
#define STM32_CAN_USE_CAN1                  FALSE
#define STM32_CAN_CAN1_IRQ_PRIORITY         11

/*
 * DAC driver system settings.
 */
#define STM32_DAC_DUAL_MODE                 FALSE
#define STM32_DAC_USE_DAC1_CH1              TRUE
#define STM32_DAC_USE_DAC1_CH2              TRUE
#define STM32_DAC_DAC1_CH1_IRQ_PRIORITY     10
#define STM32_DAC_DAC1_CH2_IRQ_PRIORITY     10
#define STM32_DAC_DAC1_CH1_DMA_PRIORITY     2
#define STM32_DAC_DAC1_CH2_DMA_PRIORITY     2

/*
 * GPT driver system settings.
 */
#define STM32_GPT_USE_TIM1                  FALSE
#define STM32_GPT_USE_TIM2                  FALSE
#define STM32_GPT_USE_TIM3                  FALSE
#define STM32_GPT_USE_TIM4                  FALSE
#define STM32_GPT_USE_TIM6                  TRUE
#define STM32_GPT_USE_TIM7                  TRUE
#define STM32_GPT_USE_TIM8                  TRUE
#define STM32_GPT_USE_TIM15                 FALSE
#define STM32_GPT_USE_TIM16                 FALSE
#define STM32_GPT_USE_TIM17                 FALSE
#define STM32_GPT_TIM1_IRQ_PRIORITY         7
#define STM32_GPT_TIM2_IRQ_PRIORITY         7
#define STM32_GPT_TIM3_IRQ_PRIORITY         7
#define STM32_GPT_TIM4_IRQ_PRIORITY         7
#define STM32_GPT_TIM6_IRQ_PRIORITY         7
#define STM32_GPT_TIM7_IRQ_PRIORITY         7
#define STM32_GPT_TIM8_IRQ_PRIORITY         7

/*
 * I2C driver system settings.
 */
#define STM32_I2C_USE_I2C1                  TRUE
#define STM32_I2C_USE_I2C2                  TRUE
#define STM32_I2C_BUSY_TIMEOUT              50
#define STM32_I2C_I2C1_IRQ_PRIORITY         10
#define STM32_I2C_I2C2_IRQ_PRIORITY         10
#define STM32_I2C_USE_DMA                   TRUE
#define STM32_I2C_I2C1_DMA_PRIORITY         1
#define STM32_I2C_I2C2_DMA_PRIORITY         1
#define STM32_I2C_DMA_ERROR_HOOK(i2cp)      osalSysHalt("DMA failure")
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

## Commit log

2019-05-26 add image of current revision
2019-05-26 add v0.3 schematic
2019-05-27 add gerber files and BOM
2019-09-22 rev3: basic setup
    [left-bottom.stl, left-top.stl, right-bottom.stl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]
2019-10-24 change issi initialization to add support for interrupts
2019-10-24 oled: proper is device ready check
2019-12-01 add updated case files for rev3
    [left-bottom.step, left-bottom.stl, left-top-v2.stl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]
2019-12-01 rev3: update gerbers
2019-12-01 rev3: remove case for now
    [left-bottom.step, left-bottom.stl, left-top-v2.stl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]
2021-01-27 add schematic for rev2
2021-01-27 add schematic for rev3
